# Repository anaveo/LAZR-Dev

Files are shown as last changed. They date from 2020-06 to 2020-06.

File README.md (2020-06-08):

# LAZR-Dev
LAZR is a remote which uses hand gestures to control functions of a TV. I undertook this project to understand IR signals and learn Autodesk Eagle, a PCB design software.

For more information click [here](https://omanavekar.wixsite.com/ommakes/lazr) to access LAZR's page on [omlabs.me](https://omanavekar.wixsite.com/ommakes)

## Components
| Plugin | Quantity | Description |
| --- | --- | --- |
| Node MCU | 1 | Microcontroller Unit |
| Flex Sensor | 5 | Sense finger movement |
| 1k Resistor | 5 | Voltage dividing resistor for flex sensor |
| 74HX4051N | 1 | Multiplexer IC for sensors |
| DIP-8 IC Socket | 1 | Multiplexer IC mount |
| Pin Header | 40 | - |
| Jumper Cable | 10 | - |
| Glove | 1 | - |
| PCB | 1 | - |

## Software
* [Arduino IDE](https://www.arduino.cc/en/main/software) - Programming environment
* [Autodesk EAGLE](https://www.autodesk.com/products/eagle/overview?plc=F360&term=1-YEAR&support=ADVANCED&quantity=1) - Schematic and PCB design software

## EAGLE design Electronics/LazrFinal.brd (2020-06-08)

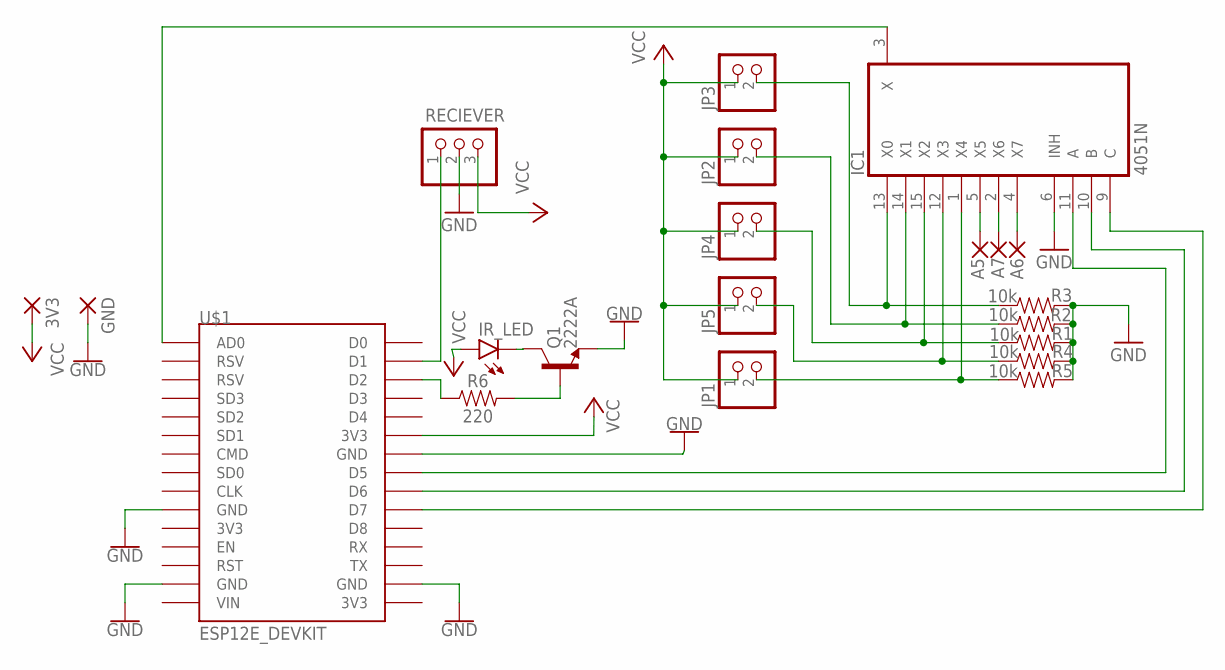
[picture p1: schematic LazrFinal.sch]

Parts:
3V3: SMD5; SMD2,54-5,08
A5, A6, A7: SMD2; SMD1,27-2,54
GND: SMD5; SMD2,54-5,08
IC1: 4051N; DIL16
IR_LED: LED-IRTSAL6100; LED_5MM
JP1, JP2, JP3, JP4, JP5: PINHD-1X2; 1X02
Q1: 2222A; TO-92
R1, R2, R3, R4, R5: 10k; AXIAL-0.3
R6: 220; AXIAL-0.3
RECIEVER: PINHD-1X3; 1X03
U$1: ESP12E_DEVKIT

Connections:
GND: GND.1, IC1.6 (INH), IC1.8 (GND), Q1.1 (E), R1.P$2 (2), R2.P$2 (2), R3.P$2 (2), R4.P$2 (2), R5.P$2 (2), RECIEVER.2, U$1.GND@0 (GND), U$1.GND@1 (GND), U$1.GND@2 (GND), U$1.GND@3 (GND)
unnamed: IC1.3 (X), U$1.AD0
unnamed: IC1.11 (A), U$1.D5
unnamed: IC1.10 (B), U$1.D6
unnamed: IC1.9 (C), U$1.D7
unnamed: IC1.13 (X0), JP3.2, R3.P$1 (1)
unnamed: IC1.14 (X1), JP2.2, R2.P$1 (1)
unnamed: IC1.15 (X2), JP4.2, R1.P$1 (1)
unnamed: IC1.12 (X3), JP5.2, R4.P$1 (1)
unnamed: IC1.1 (X4), JP1.2, R5.P$1 (1)
unnamed: R6.P$1 (1), U$1.D2
unnamed: RECIEVER.1, U$1.D1
unnamed: IR_LED.K (C), Q1.3 (C)
unnamed: Q1.2 (B), R6.P$2 (2)
unnamed: A5.1, IC1.5 (X5)
unnamed: A7.1, IC1.2 (X6)
unnamed: A6.1, IC1.4 (X7)
VCC: 3V3.1, IC1.16 (VCC), IR_LED.A, JP1.1, JP2.1, JP3.1, JP4.1, JP5.1, RECIEVER.3, U$1.3V3@1 (3V3)
VEE: IC1.7 (VEE)

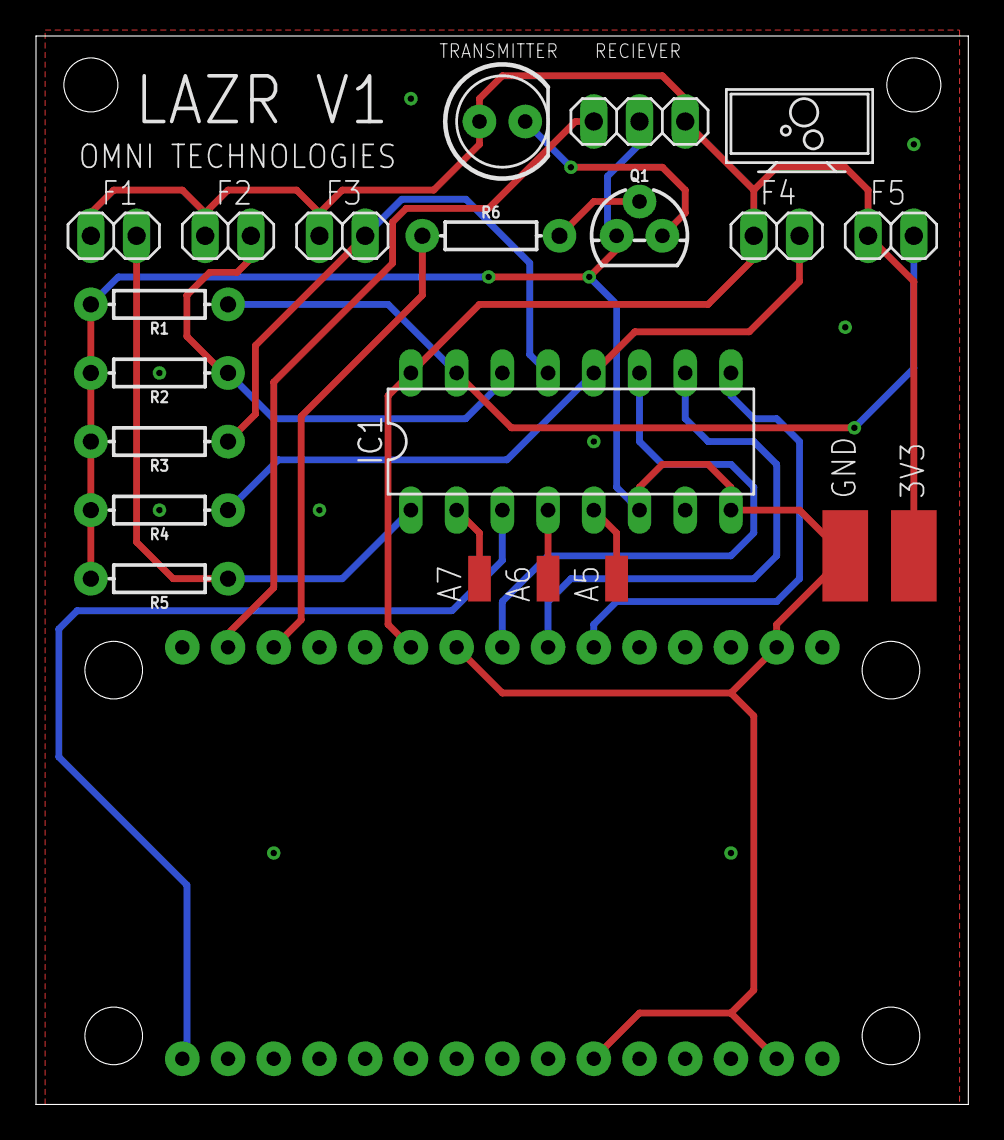
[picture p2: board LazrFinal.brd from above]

Board: 2 copper layers, 51.8 x 59.4 mm, 21 parts (0 on the bottom side), 18 nets.

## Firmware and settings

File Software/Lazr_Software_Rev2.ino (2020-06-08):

/*
LAZr Universal Remote Glove
Designed by Om Anavekar
OMNi Technologies
1/17/19
*/

#ifndef UNIT_TEST
#include <Arduino.h>
#endif
#include <IRremoteESP8266.h>
#include <IRsend.h>
#include <Wire.h>  
#include "SSD1306Wire.h"

const int MUX_A = D5;
const int MUX_B = D6;
const int MUX_C = D7;

//Each value signifies a finger
int value1 = 0;
int value2 = 0;
int value3 = 0;
int value4 = 0;
int value5 = 0;


const int ANALOG_INPUT = A0;

const uint16_t kIrLed = 4;  // ESP8266 GPIO pin to use. Recommended: 4 (D2).

IRsend irsend(kIrLed);  // Set the GPIO to be used to sending the message.

// PASTE DATA HERE
uint16_t powerOn[95] = {366, 1638,  368, 624,  388, 620,  366, 630,  350, 650,  388, 612,  362, 634,  366, 1634,  388, 612,  362, 1634,  362, 638,  362, 638,  362, 634,  362, 1634,  366, 638,  362, 47858,  362, 1642,  368, 634,  362, 638,  362, 634,  362, 638,  362, 1634,  362, 1634,  366, 638,  362, 1634,  362, 638,  368, 1630,  364, 1638,  366, 1630,  362, 638,  388, 1608,  362, 43728,  362, 1640,  362, 638,  362, 638,  362, 638,  358, 638,  362, 638,  366, 634,  362, 1634,  392, 608,  362, 1640,  362, 632,  388, 612,  362, 638,  362, 1634,  394, 606,  362}; 
uint16_t volumeUp[95] = {362, 1642,  362, 632,  372, 632,  364, 636,  362, 638,  358, 1638,  362, 638,  358, 1642,  360, 640,  358, 1642,  358, 636,  358, 642,  358, 642,  358, 1638,  358, 642,  358, 46866,  358, 1646,  358, 642,  358, 642,  358, 638,  362, 642,  358, 638,  358, 1642,  358, 640,  364, 1634,  358, 642,  358, 1638,  362, 1638,  362, 1640,  358, 636,  364, 1638,  362, 44728,  362, 1642,  362, 642,  362, 632,  362, 638,  358, 642,  358, 1638,  362, 642,  358, 1638,  362, 638,  358, 1638,  362, 638,  362, 636,  362, 638,  358, 1638,  368, 632,  362};
//Feel free to add as many data sets as you want. Just remember to give each data set a different name.

void setup() {
  //Deifne output pins for Mux
  pinMode(MUX_A, OUTPUT);
  pinMode(MUX_B, OUTPUT);     
  pinMode(MUX_C, OUTPUT);
  
  irsend.begin();
  Serial.begin(115200);
}

void changeMux(int c, int b, int a) {
  digitalWrite(MUX_A, a);
  digitalWrite(MUX_B, b);
  digitalWrite(MUX_C, c);
}

void loop() {
  changeMux(HIGH, LOW, LOW);
  value1 = analogRead(ANALOG_INPUT); //Value of the sensor connected Option 0 pin of Mux
  Serial.print("F1: "); Serial.print(value1); Serial.print(" ");

  changeMux(LOW, LOW, HIGH);
  value2 = analogRead(ANALOG_INPUT); //Value of the sensor connected Option 1 pin of Mux
  Serial.print("F2: "); Serial.print(value2); Serial.print(" ");

  changeMux(LOW, HIGH, LOW);
  value3 = analogRead(ANALOG_INPUT); //Value of the sensor connected Option 2 pin of Mux
  Serial.print("F3: "); Serial.print(value3); Serial.print(" ");

  changeMux(LOW, HIGH, HIGH);
  value4 = analogRead(ANALOG_INPUT); //Value of the sensor connected Option 3 pin of Mux
  Serial.print("F4: "); Serial.print(value4); Serial.print(" ");

  changeMux(LOW, LOW, LOW);
  value5 = analogRead(ANALOG_INPUT); //Value of the sensor connected Option 4 pin of Mux
  Serial.print("F5: "); Serial.print(value5); Serial.println(" ");

  delay(200);

//You can make as many of the functions below as you like. 
  
//DISPLAY POWER
  if(value5 >= 310) {
    irsend.sendRaw(powerOn, 95, 38);  // Send a raw data capture at 38kHz.
    delay(100);
  }

//DISPLAY VOLUME UP
    if(value2 >= 310) {
    irsend.sendRaw(volumeUp, 95, 38);  // Send a raw data capture at 38kHz.
    delay(100);
  }
  

    
  
}

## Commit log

2020-06-08 PCB file
    [LazrFinal.brd]
2020-06-08 Schematic File
    [LazrFinal.sch]

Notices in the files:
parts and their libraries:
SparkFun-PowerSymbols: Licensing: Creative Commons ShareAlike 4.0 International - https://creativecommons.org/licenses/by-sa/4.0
